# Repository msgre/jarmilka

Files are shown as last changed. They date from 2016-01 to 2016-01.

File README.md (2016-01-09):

**Jarmilka** je jednoúčelové zařízení sloužící k překopírovávání dat z SD karty
na USB disk či klíčenku. 

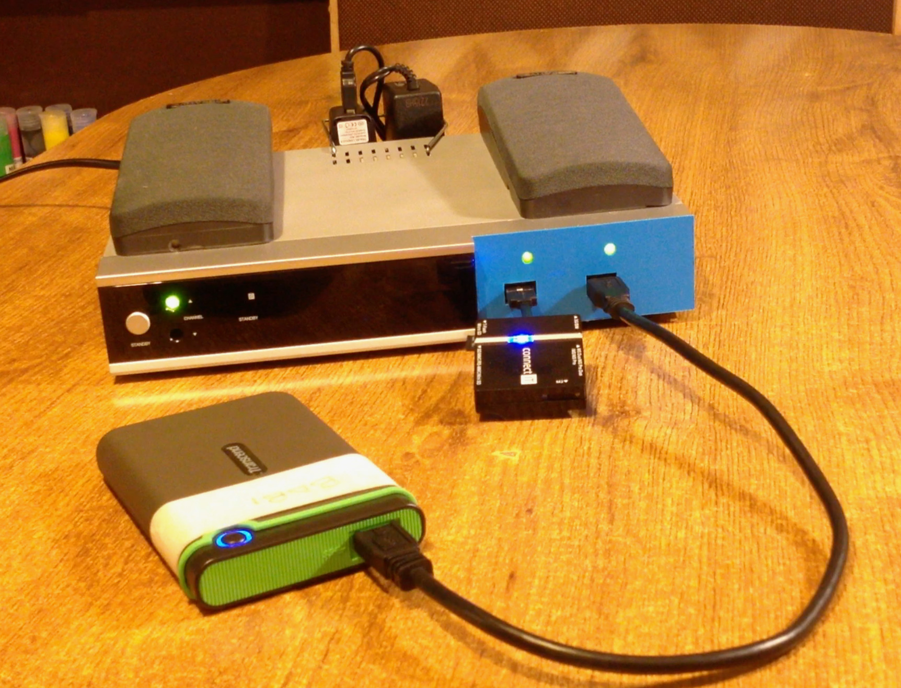
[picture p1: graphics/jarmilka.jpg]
Jarmilka v akci (https://youtu.be/zEyx_CmIOS8)


**Obsah**

* [Příběh](#p%C5%99%C3%ADb%C4%9Bh)
* [Jak to funguje](#jak-to-funguje)
* [Instalace](#instalace)
* Technické detaily
    * [Zapojení Raspberry Pi](#zapojen%C3%AD-raspberry-pi)
    * [Zapojení USB hubu](#zapojen%C3%AD-usb-hubu)
    * [Zvuky](#zvuky)
    * [Detekce vstupních zařízení](#detekce-vstupn%C3%ADch-za%C5%99%C3%ADzen%C3%AD)
    * [Procesing](#procesing)
* [Děkovačka](#d%C4%9Bkova%C4%8Dka)

# Příběh

Nevím jak u vás, ale mí rodiče poslední roky čím dál zběsileji fotí vnoučata.
Na všechno co je po ruce. Telefon(y), tablet, foťák. Po určité době se ale
dostávají do úzkých, protože nejsou schopni fotky ze zaplněných zařízení dostat
někam ven. Obvykle čekají měsíce než se u nich objevím buďto já nebo ségra, a
fotky jim stáhnem přes počítač na disk či klíčenku.

Protože se blížily vánoce a vybrat dárek pro maminu bývá peklíčko,
pokusil jsem se ji v její fotomisi pomoct. S pomocí staršího Raspberry Pi,
USB hubu, reprobedniček, tlačítka a pár LED diod jsem sestrojil jednoúčelové
zařízení, s pomocí kterého je schopná fotky na disk překopírovávat sama.

# Jak to funguje

Na Raspberry je nainstalován [jednoduchý skript v
Pythonu](application/jarmilka.py), který sleduje stav na USB sběrnici a
instruuje obsluhu k jednotlivým krokům:

* připojení zdrojové SD karty
* připojení cílového disku/USB klíčenky
* zmáčknutí tlačítka pro zahájení kopírování dat
* vytažení obou USB zařízení

Každý krok je pro lepší pochopení doplněn blikající diodou nad místem, kde se
má akce odehrát (např. pokud se má stisknout tlačítko, rozbliká se nad ním
dioda). Navíc, aby to byla větší zábava, ke každému z kroků se z reproduktorů
ozve patřičná výzva namluvená jedním z vnoučat (např. *Připoj jedničku*,
*Kopíruju, dej si kafe*, apod.)

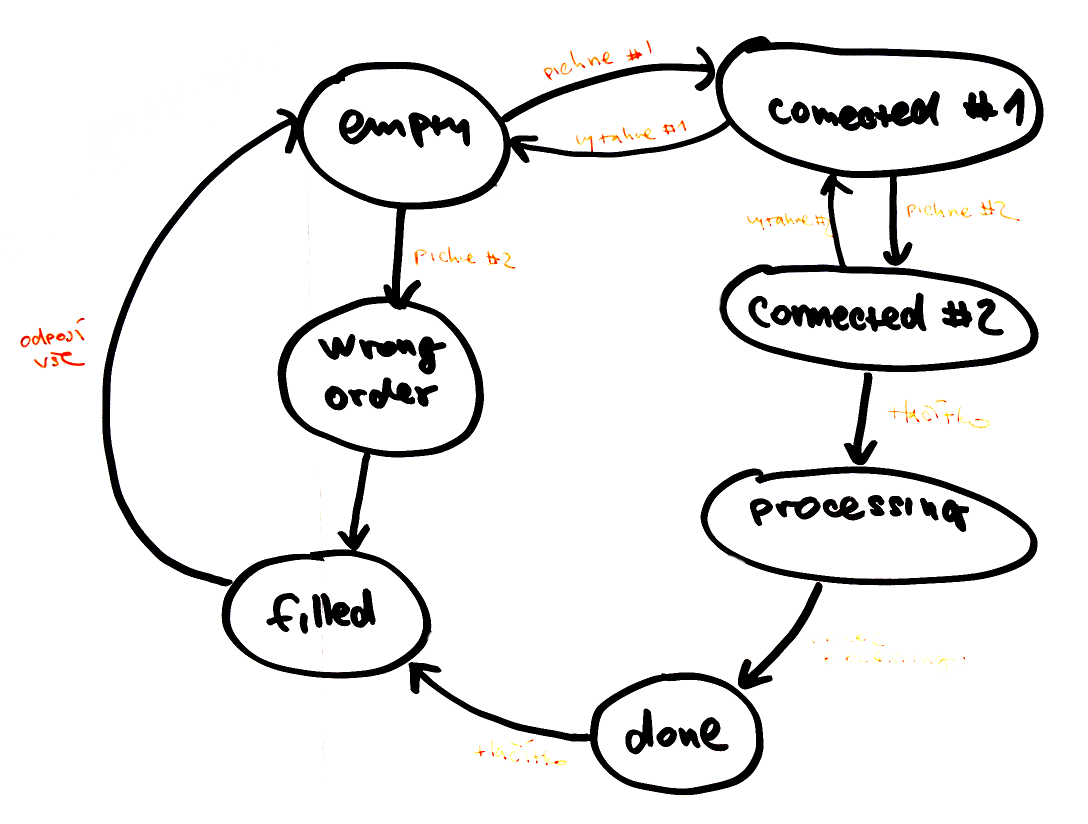
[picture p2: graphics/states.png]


Filesystém Rasbianu je nakonfigurován jako readonly, takže zařízení je odolné
vůči náhodným vypnutím (SD karty je možné velmi lehce poškodit -- pokud by během
zápisu by došlo k vypnutí, nemuselo by zařízení už nikdy nabootovat).

# Instalace

Pro snadnější (a replikovatelnou) konfiguraci RPi jsem napsal Ansible
[playbook](jarmilka.yml).  Pokud budeš chtít Jarmilku rozjet i u sebe,
nainstaluj si na svůj počítač
[Ansible](http://www.ansible.com/how-ansible-works) a pak postupuj takto:

* nainstaluj na SD kartu systém Raspbian (vyzkoušeno s Jessie Lite verze November 2015)
* připoj Raspberry Pi do sítě, nastartuj jej a zjisti jeho IP adresu
* nakopíruj dovnitř RPi svůj veřejný SSH klíč (`~/ssh/authorized_keys`)
* přejmenuj soubor `hosts.example` na `hosts` a změň v něm IP adresu podle tvé situace
* spusť příkaz `ansible-playbook jarmilka.yml`

Po dokončení posledního příkazu se RPi rebootuje a po chvíli se z něj ozve
výzva k prvnímu kroku, tj. vložení zdrojového USB zařízení s SD kartou.

# Technické detaily

## Zapojení Raspberry Pi

* SD karta se systémem a aplikací (instalace výše)
* levné reproduktory (audio výstup)
* externí USB hub (horní USB port na RPi)
* napájení Rpi

Na GPIO porty jsou připojeny LED diody a tlačítko:

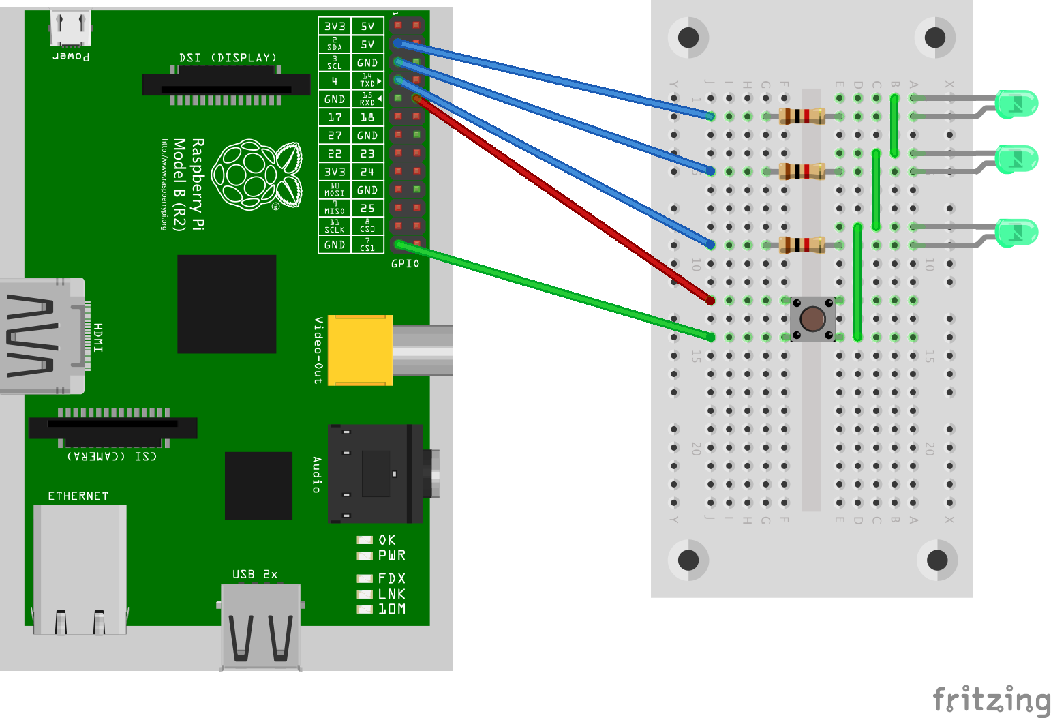
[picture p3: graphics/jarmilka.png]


* GPIO2 -- LED pro vstupní USB zařízení, viz [LED_1_PIN](application/jarmilka.py#L32)
* GPIO3 -- LED pro výstupní USB zařízení, viz [LED_2_PIN](application/jarmilka.py#L33)
* GPIO4 -- LED pro tlačítko, viz [LED_BUTTON_PIN](application/jarmilka.py#L34)
* GPIO15 -- tlačítko, viz [BUTTON_PIN](application/jarmilka.py#L36)

## Zapojení USB hubu

Raspberry Pi jsem musel dovybavit o externí USB hub, protože přímým připojením
USB zařízení (čtečka SD karet, USB disk) docházelo k restartům Raspberry.
Důvodem je, že externí periferie mohou mít větší odběry, což způsobuje pokles v
napájení Rpi a následně restarty.

Mnou použitý USB hub má celkem 7 portů (a-g), které se mapují uvnitř Rpi následovně:

    Hub, pohled z vrchu (X je napájení):

    X  a  b  c
    +--+--+--+
    |        |
    +--+--+--+
    d  e  f  g

    Řetězce identifikující jednotlivé porty:

    a: /devices/platform/soc/20980000.usb/usb1/1-1/1-1.2/1-1.2.3/1-1.2.3:1.0
    b: /devices/platform/soc/20980000.usb/usb1/1-1/1-1.2/1-1.2.4/1-1.2.4.4/1-1.2.4.4:1.0
    c: /devices/platform/soc/20980000.usb/usb1/1-1/1-1.2/1-1.2.4/1-1.2.4.3/1-1.2.4.3:1.0
    d: /devices/platform/soc/20980000.usb/usb1/1-1/1-1.2/1-1.2.1/1-1.2.1:1.0
    e: /devices/platform/soc/20980000.usb/usb1/1-1/1-1.2/1-1.2.2/1-1.2.2:1.0
    f: /devices/platform/soc/20980000.usb/usb1/1-1/1-1.2/1-1.2.4/1-1.2.4.1/1-1.2.4.1:1.0
    g: /devices/platform/soc/20980000.usb/usb1/1-1/1-1.2/1-1.2.4/1-1.2.4.2/1-1.2.4.2:1.0

V aplikaci se vyskytují dvě konstanty, které identifikují konkrétní port:

* [INPUT_USB](application/jarmilka.py#L29) -- identifikátor vstupního USB zařízení
* [OUTPUT_USB](application/jarmilka.py#L30) -- identifikátor výstupního USB zařízení

Je velmi pravděpodobné, že v tvé situaci budou mít zařízení jiné identifikátory.
(vlastní hodnoty odhalíš pohledem do `/var/log/syslog` uvnitř RPi).

## Zvuky

V adresáři [sounds/](application/sounds/) je sada WAV souborů pro jednotlivé
fáze kopírování.  Soubory jsou pojmenovány podle klíče `stav_cislo.wav`, kde
`stav` odpovídá konkrétnímu stavu aplikace a `cislo` označuje
variantu hlášky (každá z variant je namluvena jedním z vnoučat).

Např. zpráva *Připoj jedničku* existuje ve 3 variantách (`one_01.wav`,
`one_02.wav`, `one_03.wav`). Aplikace Jarmilka si pak náhodně vybírá některou 
z nich.

Pokud budeš do sady zvuků zasahovat, možná budeš muset aktualizovat slovník
[SOUNDS](application/jarmilka.py#L118).

## Detekce vstupních zařízení

Během připojování USB se kontroluje nejen port, kam bylo zařízení připojeno
(chceme aby vstupní čtečka byla v prvním portu a disk v druhém), ale také 
struktura filesystému.

Aktuálně aplikace dokáže rozpoznat 2 typy SD karet.

Android telefon:

    Android
    DCIM
        100ANDRO
        Camera
            ./Camera/IMG_20150619_190421.jpg
            ./Camera/VID_20150619_190427.mp4
    HuaweiBackup
    HwOUC
    HWThemes
    LOST.DIR

Fotoaparát Canon:

    DCIM
        119___06
        120___07
            IMG_0357.JPG
            IMG_0358.JPG
            IMG_0360.JPG
            MVI_0376.MOV
        121___12

## Procesing

Jakmile aplikace detekuje připojení obou zařízení ve správných portech, zahájí
se processing. V aktuální verzi se provede pouze překopírování obsahu s pomocí
aplikace `rsync`. V budoucnu ale možná doplním převzorkování obrázků na 
menší velikosti kvůli rychlejšímu prohlížení na televizi.
    
Samotné kopírování je vcelku pomalé, protože probíhá přes USB hub zapojený
do jediného RPi USB portu. Konkrétní rychlosti závisí také na typu SD karty.
Pro orientaci: 1 GB dat se v mých podmínkách přesunulo za cca 8.5 minuty
(tj. ~2 MB/s).

# Děkovačka

* [Vlastíkovi](https://github.com/slintak) za rady ohledně nastavení readonly filesystému
* Tatovi za vykuchání starého satelitu a zapouzdření chumlu drátů do jeho útrob

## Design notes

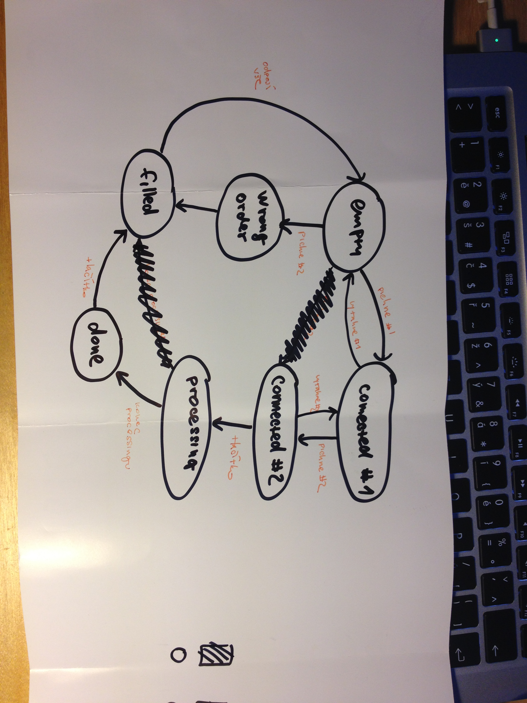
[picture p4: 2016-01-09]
graphics/states.jpg

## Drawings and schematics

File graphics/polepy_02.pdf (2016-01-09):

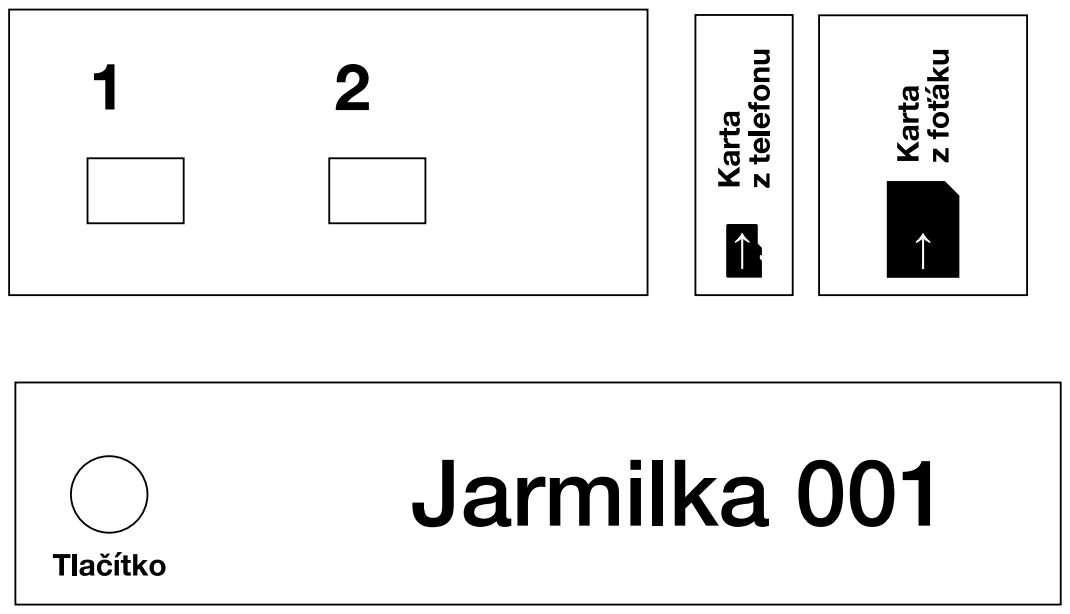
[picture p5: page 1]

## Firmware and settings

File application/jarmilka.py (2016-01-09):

# -*- coding: utf-8 -*-

import logging
import os
import random
import re
import shlex
import subprocess
import time

import RPi.GPIO as GPIO

logging.basicConfig()
logger = logging.getLogger(__name__)
logger.setLevel(logging.DEBUG)

from pyudev import Context

DEBUG = False

RED = '\033[91m'
GREEN = '\033[92m'
YELLOW = '\033[93m'
LIGHT_PURPLE = '\033[94m'
PURPLE = '\033[95m'
END = '\033[0m'

# hard coded defaults
INPUT_USB  = '/devices/platform/soc/20980000.usb/usb1/1-1/1-1.2/1-1.2.1/1-1.2.1:1.0'
OUTPUT_USB = '/devices/platform/soc/20980000.usb/usb1/1-1/1-1.2/1-1.2.4/1-1.2.4.1/1-1.2.4.1:1.0'

LED_1_PIN = 2
LED_2_PIN = 3
LED_BUTTON_PIN = 4

BUTTON_PIN = 15

WAIT = 0.3

def setup_gpio():
    """
    Setup GPIO pins on which LEDs and button switch are connected.
    """
    GPIO.setmode(GPIO.BCM)
    GPIO.setwarnings(False)

    # led output
    GPIO.setup(LED_1_PIN, GPIO.OUT)
    GPIO.setup(LED_2_PIN, GPIO.OUT)
    GPIO.setup(LED_BUTTON_PIN, GPIO.OUT)

    # button input
    GPIO.setup(BUTTON_PIN, GPIO.IN, GPIO.PUD_UP)

    # switch leds off
    reset_led()

def reset_led(which=None):
    """
    Switch off all or only selected LEDs.
    """
    if not which:
        GPIO.output(LED_1_PIN, 0)
        GPIO.output(LED_2_PIN, 0)
        GPIO.output(LED_BUTTON_PIN, 0)
    else:
        for pin in which:
            GPIO.output(pin, 0)

def get_usb_devices(context):
    """
    Get info about monitored USB devices.
    """
    out = []
    for device in context.list_devices(subsystem='usb'):
        if device.device_path not in [INPUT_USB, OUTPUT_USB]:
            continue
        out.append(device.device_path)
    return out


USB_DRIVE_RE = re.compile(r'^(/dev/[0-9a-z]+) (/media/usb[0-9]+) .+$')

def get_mounted_drives():
    """
    Get info about mounted devices.
    """
    with open('/etc/mtab') as f:
        out = [USB_DRIVE_RE.search(i).groups() for i in f.readlines() if USB_DRIVE_RE.search(i)]
    return out


def call_command(cmd, cwd=None, timeout=None, wait=False):
    """
    Helper function for calling given command.
    """
    args = shlex.split(cmd)
    p = subprocess.Popen(args, stdout=subprocess.PIPE, cwd=cwd)

    if timeout:
        t = 0
        delta = 0.1
        while t < timeout:
            time.sleep(delta)
            t = t + 0.1
            if p.poll() is not None:
                break
        if p.poll() is None:
            p.kill()

    if wait:
        (stdout, stderr) = p.communicate()
        return p.returncode == 0, stdout.strip()
    return None, None


SOUNDS_DIR = '/application/sounds/'
SOUNDS = {
    'one':
        ['one_01.wav', 'one_02.wav', 'one_03.wav',],
    'two':
        ['two_01.wav', 'two_02.wav', 'two_03.wav',],
    'button':
        ['button_01.wav', 'button_02.wav', 'button_03.wav',],
    'done':
        ['done_01.wav', 'done_02.wav', 'done_03.wav', 'done_04.wav',],
    'processing':
        ['processing_01.wav', 'processing_02.wav', 'processing_03.wav',],
    'eject':
        ['eject_01.wav', 'eject_02.wav',],
    'problem':
        ['problem_01.wav', 'problem_02.wav', 'problem_03.wav',],
}

def play(sound):
    idx = random.randint(0, len(SOUNDS[sound])-1)
    path = os.path.join(SOUNDS_DIR, SOUNDS[sound][idx])
    command = '/usr/bin/aplay %s' % path
    call_command(command)


# ------------------------------------------

DATA = {}
FROM_DRIVE = None
FROM_DEVICE = None
FROM_PATH = None
TO_DRIVE = None
TO_DEVICE = None
TO_PATH = None

def update_state_data(state, **kwargs):
    global DATA
    for k, v in kwargs.items():
        if state not in DATA:
            DATA[state] = {}
        DATA[state][k] = v

def set_state(state, data=None):
    logger.debug("Setting state %s with data %s." % (state, str(data)))
    if data:
        update_state_data(state, **data)
    return state


# empty

PHOTO_RE = re.compile(r'^\d{3}___\d{2}$') # ie "119___06"

def set_state_empty(silent=False):
    reset_led()
    if not silent:
        play('one')
    return set_state('empty', {'blink': [LED_1_PIN]})

def process_state_empty(state, context, data, silent=False):
    devices = get_usb_devices(context)
    if INPUT_USB in devices:
        logger.debug("Source USB device recognised.")
        GPIO.output(LED_1_PIN, 1)
        mounted = get_mounted_drives()
        logger.debug("List of mounted drives: %s" % ", ".join(map(str, mounted)))
        if len(mounted) == 1:
            logger.info("Source USB device mounted.")
            global FROM_DEVICE
            global FROM_DRIVE
            global FROM_PATH
            global TO_PATH
            FROM_DEVICE = mounted[0][0]
            FROM_DRIVE = mounted[0][1]
            # recognise type of source media
            if 'DCIM' not in os.listdir(FROM_DRIVE):
                # source drive is something unknown
                logger.debug("Source drive doesn't have DCIM directory. Does it really came from camera/phone?")
                state = set_state_problem()
            files = os.listdir(os.path.join(FROM_DRIVE, 'DCIM'))
            if 'Camera' in files:
                # source drive is from phone
                logger.info("Source drive seems like Android phone.")
                FROM_PATH = 'DCIM/Camera'
                TO_PATH = 'originaly/telefon'
                state = set_state_connected_1()
            elif any([i for i in files if PHOTO_RE.match(i)]):
                # source drive is from camera
                logger.info("Source drive seems like Camera.")
                FROM_PATH = 'DCIM'
                TO_PATH = 'originaly/fotak'
                state = set_state_connected_1()
            else:
                # source drive is something unknown
                logger.warn("Source drive wasn't recognised.")
                logger.warn("File list: %s" % ", ".join(map(str, files)))
                state = set_state_problem()

    elif OUTPUT_USB in devices:
        logger.info("Wrong order of mounting: expect connecting of source drive, but destination was mounted first.")
        reset_led()
        mounted = get_mounted_drives()
        if len(mounted) == 1:
            state = set_state_problem()
    return state

# connected_1

def set_state_connected_1(silent=False):
    if not silent:
        play('two')
    return set_state('connected_1', {'blink': [LED_2_PIN]})

def process_state_connected_1(state, context, data, silent=False):
    devices = get_usb_devices(context)
    if OUTPUT_USB in devices:
        logger.debug("Destination USB device recognised.")
        GPIO.output(LED_2_PIN, 1)
        mounted = get_mounted_drives()
        logger.debug("List of mounted drives: %s" % ", ".join(map(str, mounted)))
        if len(mounted) == 2:
            logger.info("Destination USB device mounted.")
            mounted = [i for i in mounted if i[1] != FROM_DRIVE]
            global TO_DEVICE
            global TO_DRIVE
            TO_DEVICE = mounted[0][0]
            TO_DRIVE = mounted[0][1]
            # recognise type of destination media
            files = os.listdir(TO_DRIVE)
            if 'fotky' in files and \
               'videa' in files and \
               'originaly' in files:
                # destination drive is USB HDD
                logger.info("Destination drive seems like known USB HDD.")
                state = set_state_connected_2()
            else:
                # there is something as destination drive, but it doesn't look familiar
                logger.warn("Destination drive wasn't recognised.")
                logger.warn("File list: %s" % ", ".join(map(str, files)))
                state = set_state_problem()

    elif INPUT_USB not in devices:
        logger.info("Wrong order of mounting: expect connecting of destination drive, instead source was unmounted.")
        reset_led()
        state = set_state_empty()
    return state

# connected_2

def set_state_connected_2(silent=False):
    if not silent:
        play('button')
    return set_state('connected_2', {'blink': [LED_BUTTON_PIN]})

def process_state_connected_2(state, context, data, silent=False):
    devices = get_usb_devices(context)
    if INPUT_USB in devices and OUTPUT_USB in devices:
        logger.debug('Both devices (source and destination) prepared, waiting for button.')
        GPIO.output(LED_BUTTON_PIN, 1)
        if not GPIO.input(BUTTON_PIN):
            logger.info('Button pressed.')
            state = set_state_processing()
    else:
        logger.warn('Some of the device is not connected, devices %s' % ", ".join(devices))
        reset_led([LED_2_PIN])
        state = set_state_connected_1()
    return state

# problem

def set_state_problem(silent=False):
    if not silent:
        play('problem')
    return set_state('problem')

def process_state_problem(state, context, data, silent=False):
    state = set_state_filled()
    return state

# processing

def set_state_processing(silent=False):
    if not silent:
        play('processing')
    return set_state('processing')

def process_state_processing(state, context, data, silent=False):
    source = os.path.join(FROM_DRIVE, FROM_PATH) + '/'
    destination = os.path.join(TO_DRIVE, TO_PATH) + '/'

    # copy files
    command = 'sudo /usr/bin/rsync -r %s %s' % (source, destination)
    logger.debug('Copying files: %s' % command)
    call_command(command, wait=True)

    # unmount devices
    logger.debug('Unmounting device %s' % FROM_DEVICE)
    call_command('sudo umount %s' % FROM_DEVICE, wait=True)
    logger.debug('Unmounting device %s' % TO_DEVICE)
    call_command('sudo umount %s' % TO_DEVICE, wait=True)

    state = set_state_done()
    return state

# done

def set_state_done(silent=False):
    if not silent:
        play('done')
    return set_state('done', {'blink': [LED_BUTTON_PIN], 'pause': 10, 'i': 0})

def process_state_done(state, context, data, silent=False):
    """
    cekani na tlacitko
    counter
    dokola "hotovo"
    blikani
    """
    logger.debug('Processing is done, waiting for button press.')
    if not GPIO.input(BUTTON_PIN):
        logger.info('Button pressed.')
        state = set_state_filled()
    else:
        if data['i'] > data['pause']:
            play('done')
            update_state_data('done', i=0)
        else:
            update_state_data('done', i=data['i'] + WAIT)
    return state

# filled

def set_state_filled(silent=False):
    reset_led()
    if not silent:
        play('eject')

    return set_state('filled')

def process_state_filled(state, context, data, silent=False):
    devices = get_usb_devices(context)
    mounted = get_mounted_drives()

    if len(devices) == 0 and len(mounted) == 0:
        state = set_state_empty()
    elif mounted:
        for device in mounted:
            logger.debug('Unmounting device %s' % device[0])
            call_command('sudo umount %s' % device[0], wait=True)

    return state


setup_gpio()

context = Context()

STATES = {
        'empty': process_state_empty,
        'connected_1': process_state_connected_1,
        'connected_2': process_state_connected_2,
        'problem': process_state_problem,
        'processing': process_state_processing,
        'done': process_state_done,
        'filled': process_state_filled,
}

blink = 0
state = set_state_filled(silent=True)
state = STATES[state](state, context, DATA.get(state, None), silent=True)
if state == 'filled':
    state = set_state_filled()

while True:
    state = STATES[state](state, context, DATA.get(state, None))
    if state in DATA and 'blink' in DATA[state]:
        for pin in DATA[state]['blink']:
            GPIO.output(pin, blink)
    time.sleep(WAIT)
    blink = 0 if blink else 1
